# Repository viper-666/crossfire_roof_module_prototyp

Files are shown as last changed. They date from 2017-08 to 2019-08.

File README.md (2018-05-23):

# XF Roof Module

Deutsche Anleitung: [LIESMICH.md](https://github.com/viper-666/xf_roof_module/blob/master/LIESMICH.md)

This module allows you to open / close the Crossfire's soft top without having to press and hold the Open / Close button all the time.

Another feature is that you can set up the speed at which you can do this in the Arduino Sketch.
The default is 31 mph (50 kph) (variable "int GESCHWINDIGKEIT = 50" attention it is in kph not in mph) and should not be increased. If the speed at which you open the soft top is too high, this will damage your convertible top or the mechanics.

In addition, the windows are automatically raised after the convertible top is opened.
There is also an emergency stop function simply push the button, no matter which direction, again and the roof stops.

I have tested the module for several months without problems but it could damage your car. Therefore, a replica is done at your own risk!

## Handling

If you want to open or close the roof while the car stands simply press the switch short in the appropriate direction. It can take up to 2 seconds before the roof moves. If an error occurs it will piping.
During the journey, you can open or close the roof up to the set speed. 

Please note the following:

If you want to open the roof while driving, it is very important first to press the switch open and then to unlock the roof within 2 seconds.
If you unlock the roof first, the original CrossFire convertible module is interrupted and you have to close the roof again and wait a few seconds until you can open it.

When closing while driving up to the set speed, there is nothing else to do, just press the switch on close and after about 2 seconds the roof will close.
If you get over the set speed while opening or closing, the roof stops moving and you have to speed down under the set speed and the roof will complete the action.

## Lets start

First you have to build the hardware, so solder the board. Unfortunately, I do not have the knowledge to design a circuit board which you can etch.
But if you have created such a circuit board, please give me the file, I make the layout available so that everyone else can benefit from it.

Until then you have to build the circuit unfortunately as I on a perfboard.

## BOM Hardware

|Microcontroler:| |
|---|---|
|Value		|Quantily|
|Arduino Nano V3|1 |

|Resistors:| |
|---|---|
|Value|Quantily|
|1M |1 |
|2k2 |3 |
|5k |2 |
|22k |5 |
|100k |5 |
|560k |1 |
|200 |1 |

|Zener Diode:| |
|---|---|
|Value|Quantily|
|1N750 (4,7V)|1|

|Diode:| |
|---|---|
|Value|Quantily|
|1N4007|1|

|Voltage regulator:| |
|---|---|
|Value|Quantily|
|78L05Z (5V) TO92|1|

|Capacitors:| |
|---|---|
|Value|Quantily|
|100µF|2|
|100n|2|

|Transistors:| |
|---|---|
|Value|Quantily|
|BC547|5|

|Fuse:| |
|---|---|
|Value|Quantily|
|200mA|1|
|Fuse holder|1|

|Plug and socket:| |
|---|---|
|Value|Quantily|
|TE Connectivity AMP 1-1586041-4 VAL-U-LOK CONN HEADER 14POS R/A W/O PEGS|1 or 2|
|TE Connectivity AMP 1-1586019-4 VAL-U-LOK CONN RCPT HOUSING 14POS 4.2MM|1 or 2|
|TE Connectivity AMP 1586315-1 CONN TERM SOCKET 18-22AWG TIN|14 or 28|

But you can take any other socket and plug as long as they have at least 8 contacts.

## Building the hardware

A perfboard measuring 77mm x 80mm is required for assembly.

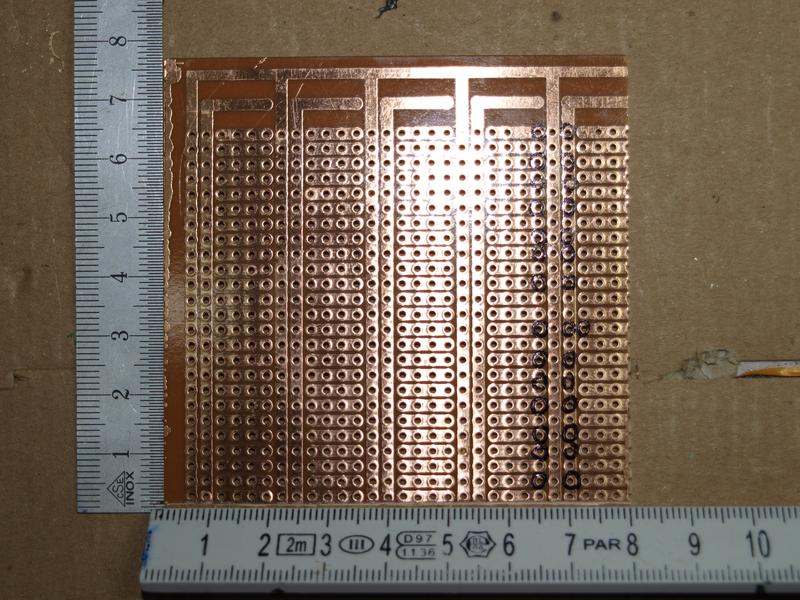
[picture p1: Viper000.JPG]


First I soldered the two sockets. For the roof module only the lower one is required, the upper one guides the other inputs and outputs of the Arduino Nano to the outside. This I have made for future extensions of the functions.
In order for the socket to fit, the holes of the circuit board must be inflated.

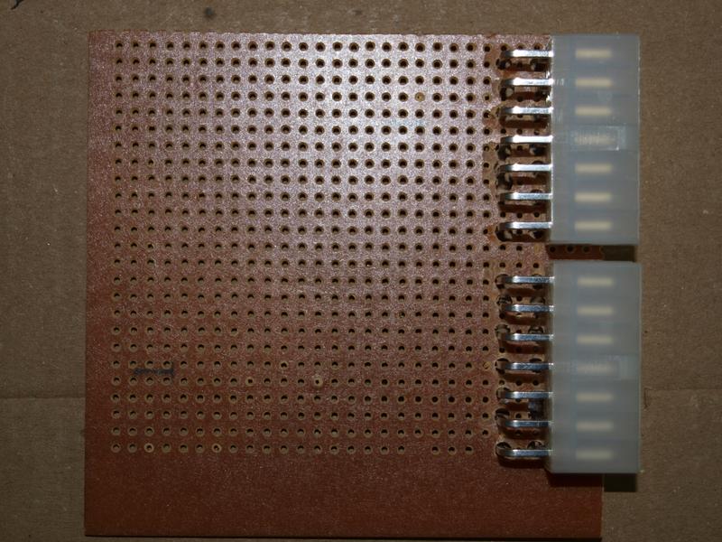
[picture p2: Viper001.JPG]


Subsequently, I have constructed the board according to the [schematic](https://github.com/viper-666/xf_roof_module/blob/master/Dachmodul.pdf):

At the bottom of the Arduino Nano, on the right the 12-18V to 5V voltage conversion and next to the fuse holder.
Above the Arduinno Nano the 5 transistors with the associated components.
Then make the missing connections with cables. And do not let the cable chaos deter you. 

You can omit the green socket and the cabling if you want to do without the extensibility to additional other functions.

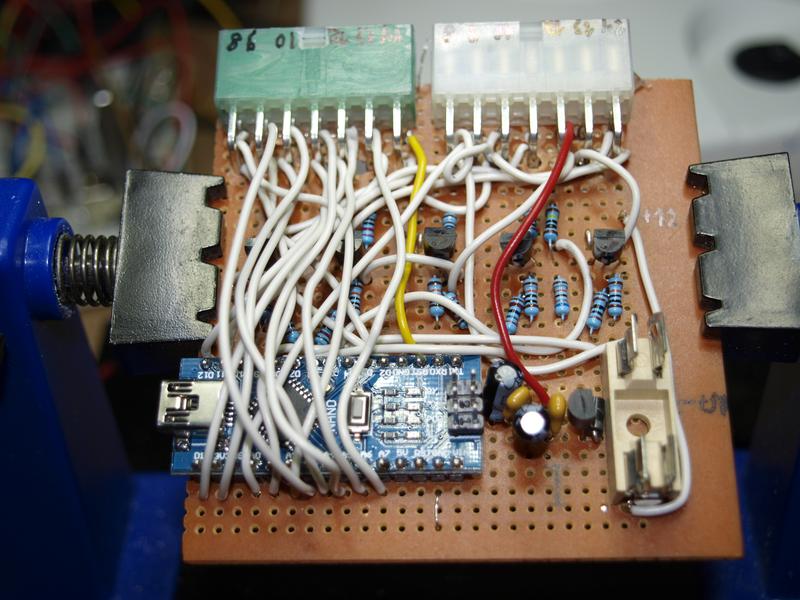
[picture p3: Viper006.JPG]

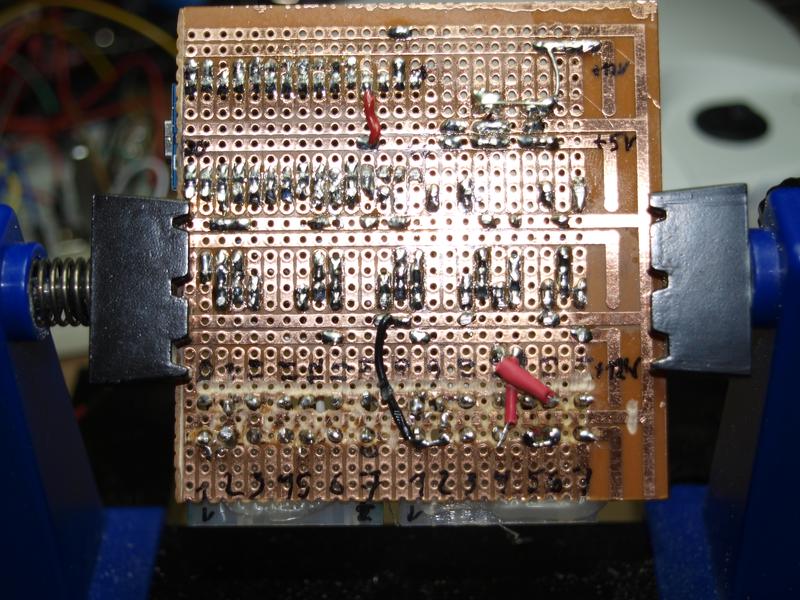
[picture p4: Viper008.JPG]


The plug with the cables is created according to the following [schema](https://github.com/viper-666/xf_roof_module/blob/master/Wiring.pdf) and integrated into the Crossfire cable harness.
The PINs marked in blue belong to the corresponding PINs of the connector.
The pins for the plug should be crimped onto the stripped cable ends with a crimping tool. If you do not have a crimping pliers, it is cheap, you can get it for 10-20 $ or you can solder the cable ends with the pins.

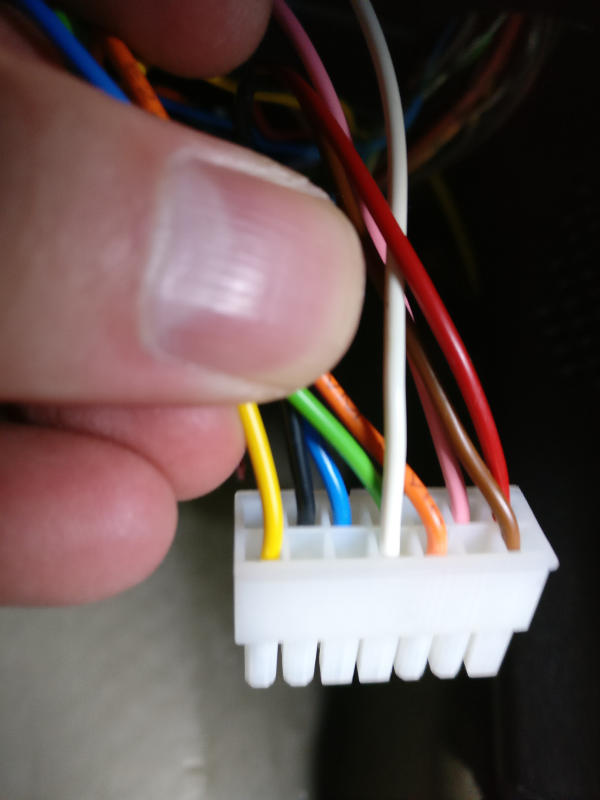
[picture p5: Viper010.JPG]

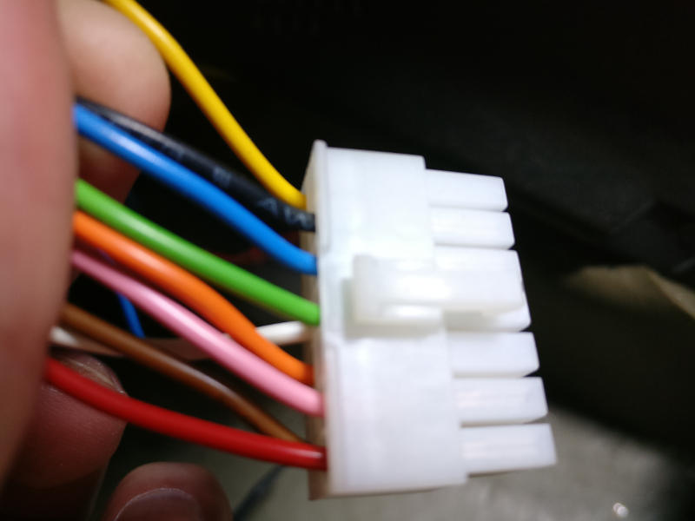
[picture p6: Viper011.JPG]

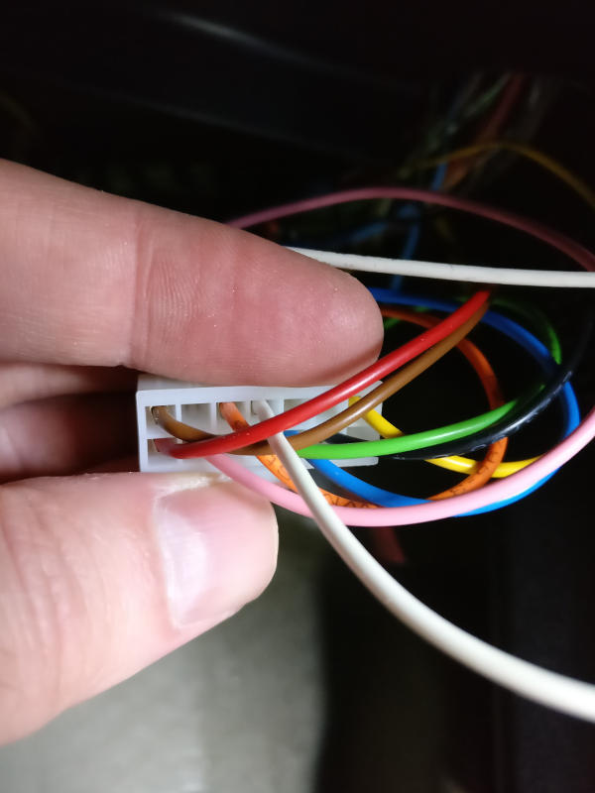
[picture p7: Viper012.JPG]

Build of the prototyp-PCB

This is how the finished module with the printed housing looks like:

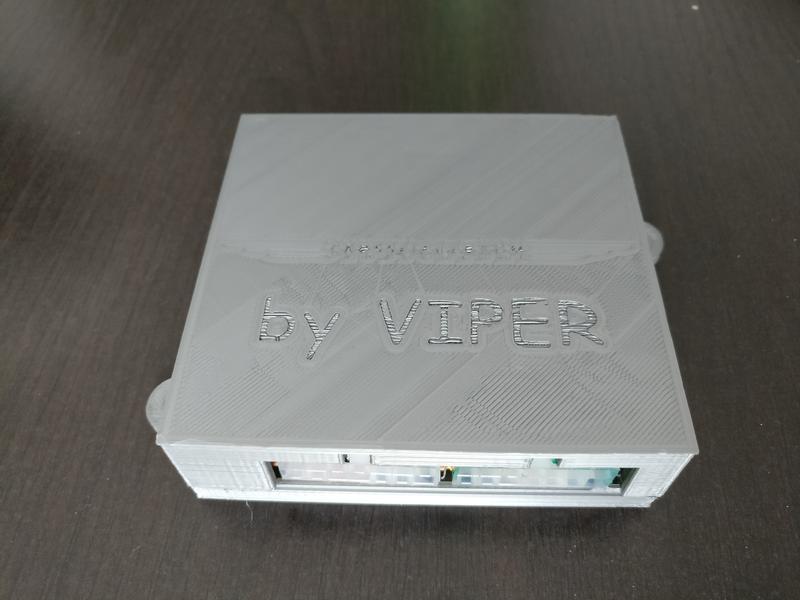
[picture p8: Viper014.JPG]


I recommend the construction of a deactivation plug, which is inserted in case of problems or sale of the car instead of the roof module. Thus, the severed lines are reconnected and the "original state" is restored.
Simply connect the following pins for a socket:

|A|B|
|---|---|
|PIN 3|PIN 11|
|PIN 7|PIN 12|
|PIN 9|PIN 13|

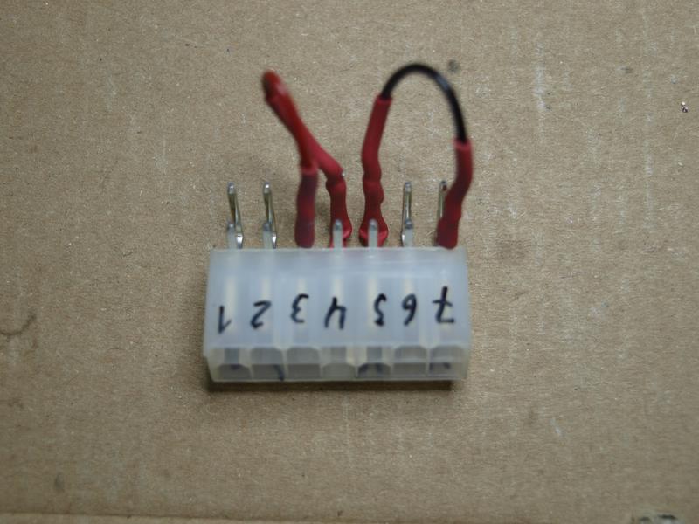
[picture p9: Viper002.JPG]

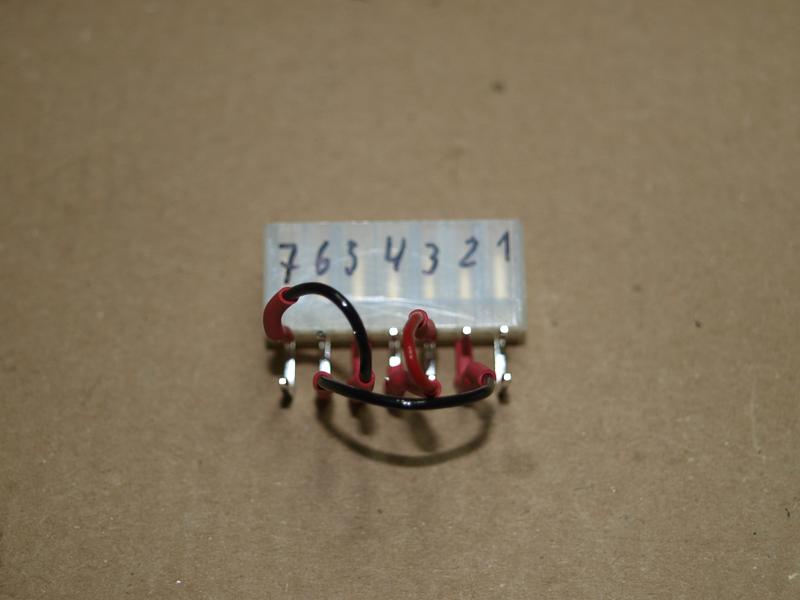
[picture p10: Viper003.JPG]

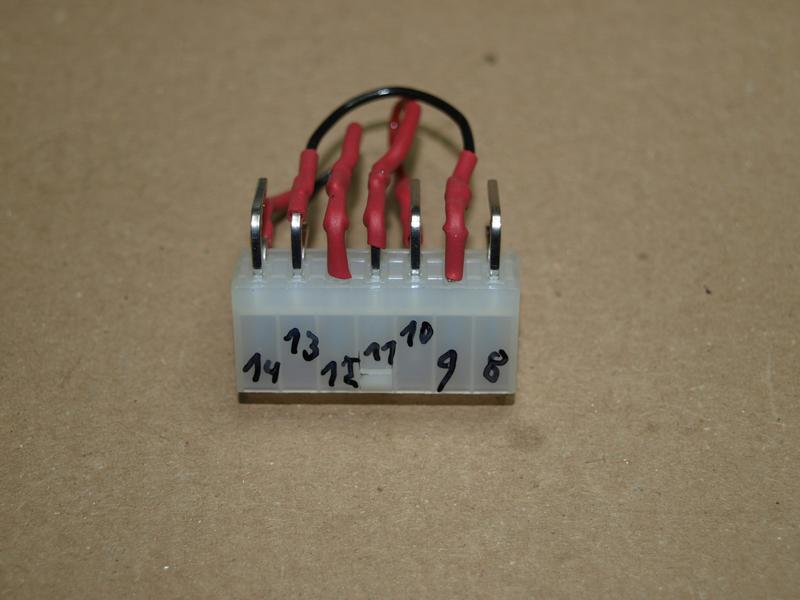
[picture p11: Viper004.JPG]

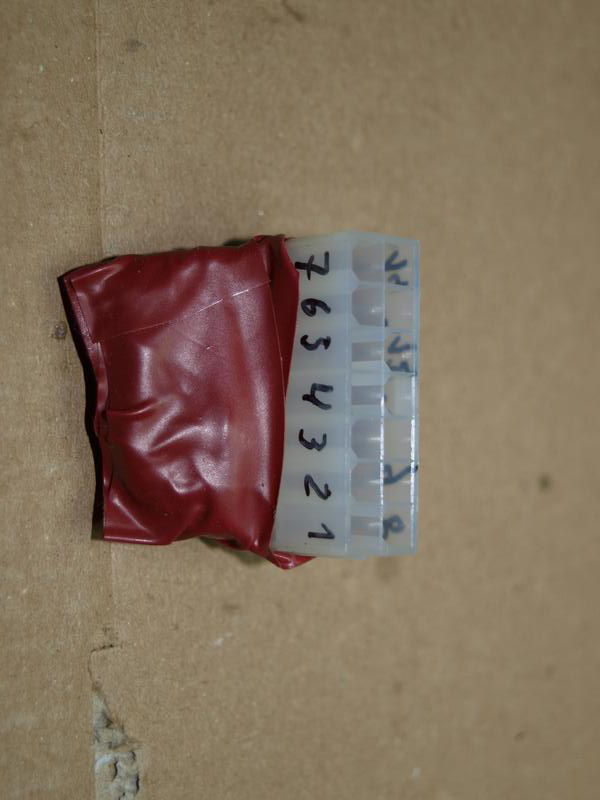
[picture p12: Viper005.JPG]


## Installing of the firmware

Simply use the [Sketch](https://github.com/viper-666/xf_roof_module/blob/master/Crossfire_Dachmodul-4.ino) with the [ARDUINO IDE](https://www.arduino.cc/en/Main/Software) to the Arduino.

## Installation in the Crossfire

The plug created in the previous section with the cables is now wired according to the following [schema](https://github.com/viper-666/xf_roof_module/blob/master/Wiring.pdf) in the Crossfire.

I recommend soldering the cables and isolating them with a shrink tube.

We start at the roof switch. To get to the roof switch, open the cup holder, grasp the opening with the fingers and lift the silver bezel at the front of the circuit until it is released from the grid.

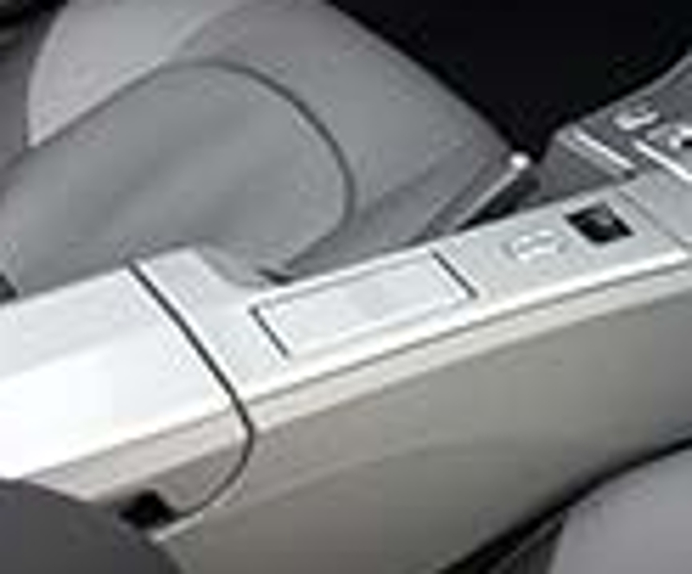
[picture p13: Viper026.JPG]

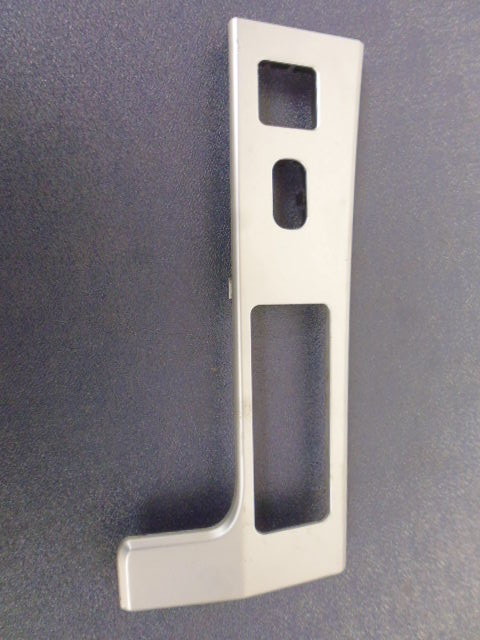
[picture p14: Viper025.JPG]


The white / purple cable must then be cut and the pink cable of our plug must be connected with the part of the white / purple cable which is still hanging on the plug. The black cable of the plug comes to the now still open end of the white / purple cable.
The white cable of our plug comes to the brown / yellow cable.

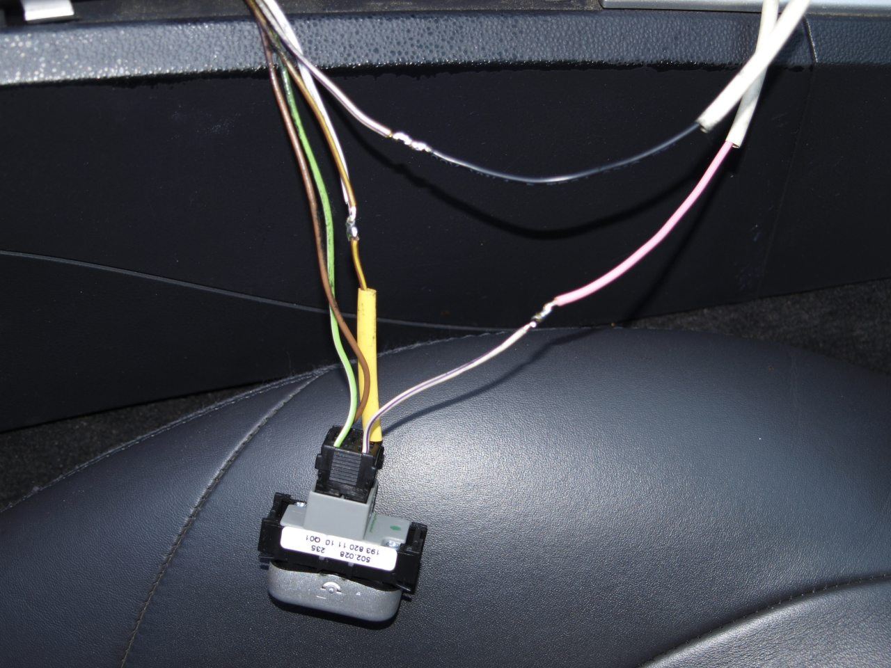
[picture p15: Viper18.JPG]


Now we have to lift the carpet in the passenger footwell and fold in the direction of the seat and remove the white styrophoric plate.

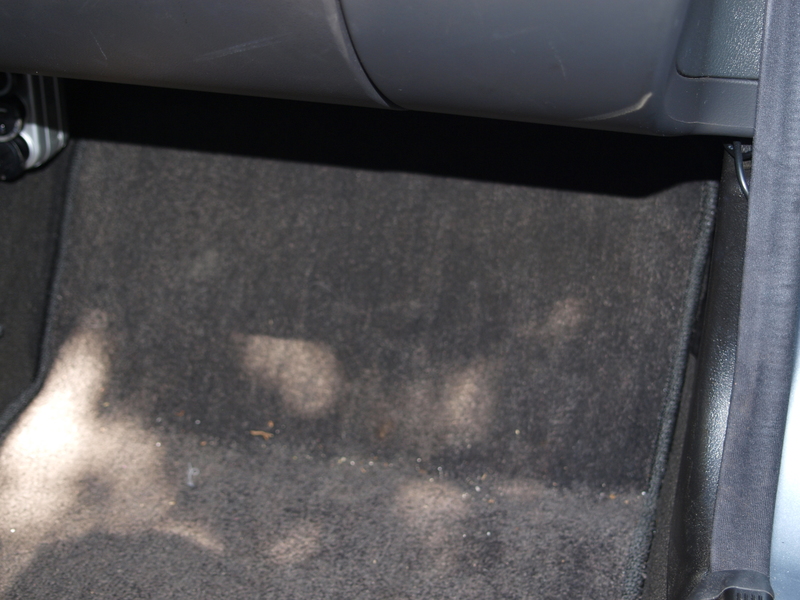
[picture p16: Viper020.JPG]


The silver plate is secured with 3 black plastic nuts, which must be removed.

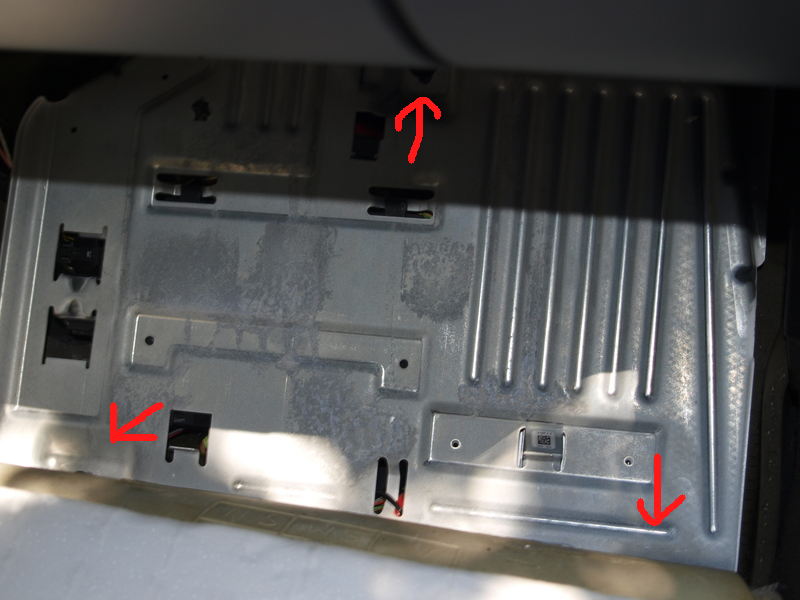
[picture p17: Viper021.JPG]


Now we can fold this towards the seat. The wiring harness with the required cables is on the upper right.

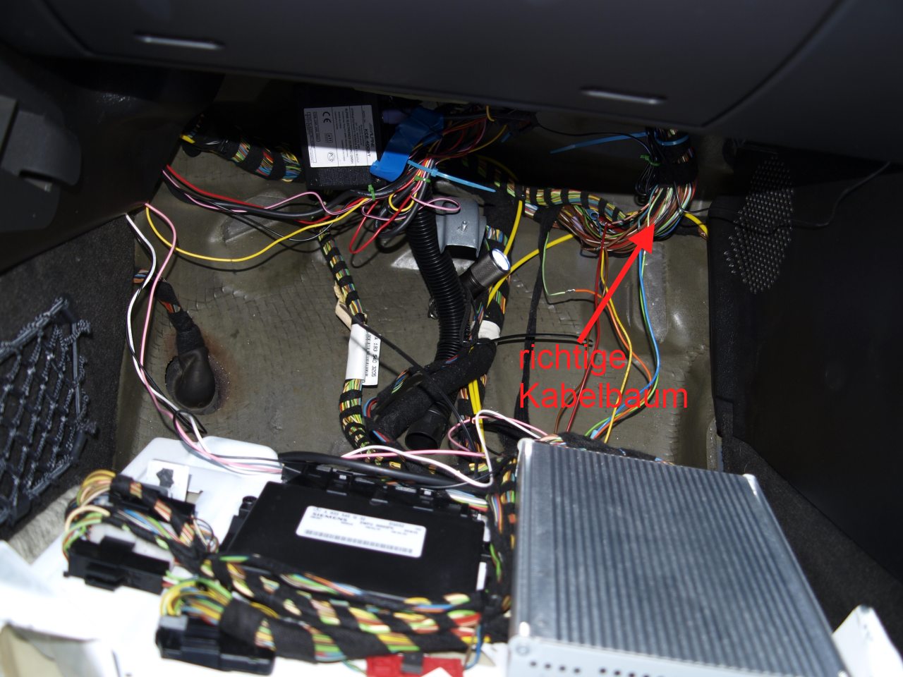
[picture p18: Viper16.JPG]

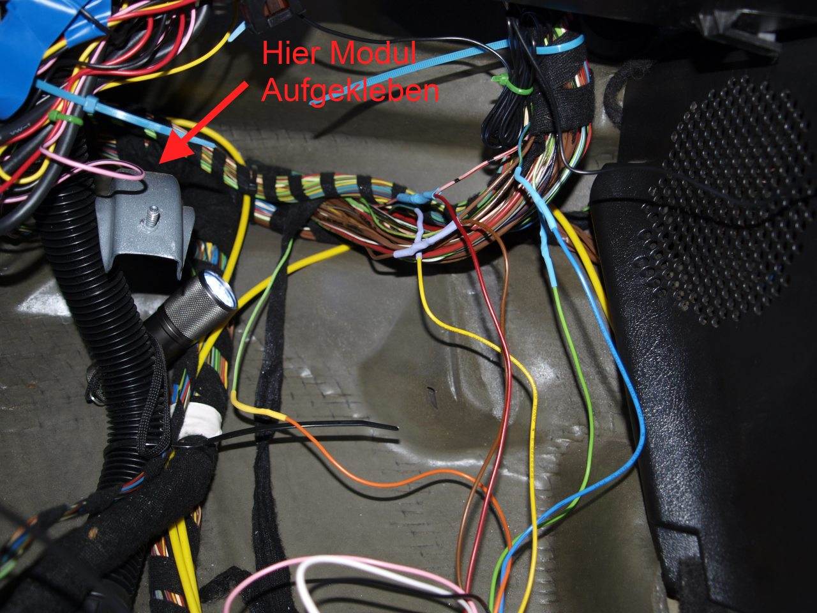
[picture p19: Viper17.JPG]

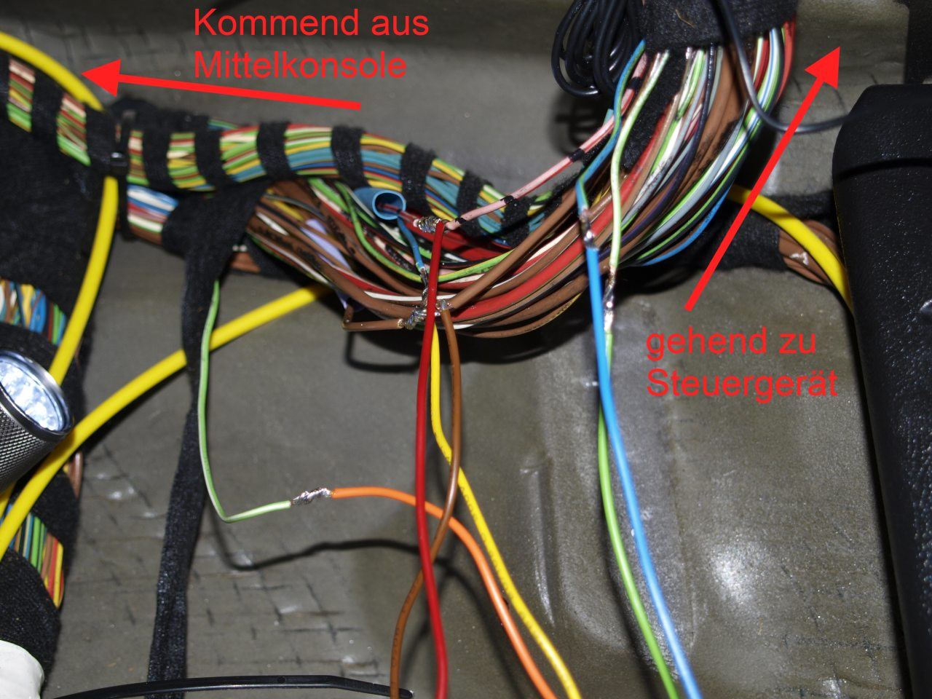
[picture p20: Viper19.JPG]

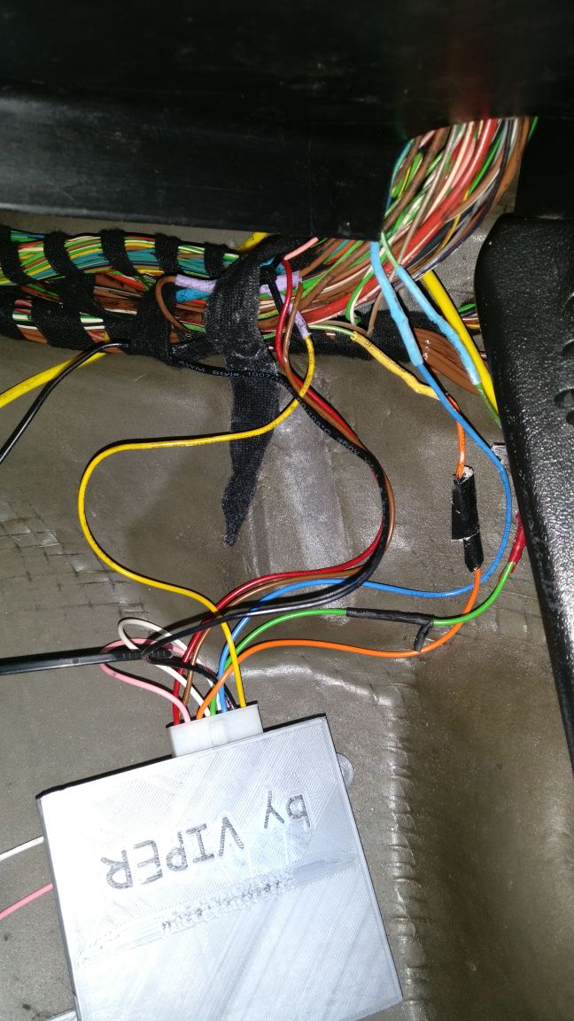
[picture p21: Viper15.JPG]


In this harness we have to look for the following cables:
- Pink / Red / Black (+ 12V) which we connect with the red cable of the plug
- Brown (ground) this we will connect with the brown cables of the plug
- Blue / Green (BCM PIN 56) this must be cut through and the cable end which goes to the left to the center console comes the yellow and to the other end the blue cable of the plug
- Green / White (BCM PIN 74) you have to be careful, the cable is available several times. It is best to test with a multimeter in the continuity test whether the correct cable from the control unit PIN 74 has caught. Then this must cut through and to the cable end which goes to the left to the center console comes the orange and to the other end the green cable of the plug

If there is still enough space in the box for the RCM module and the control unit, the cables can also be tapped directly at the connector of the control unit and you only have to pass the three cables for the roof switch through the cable harness.
Advantage is, the better accessibility and one the cables unambiguously at the connector finds, since there the PIN numbers are readable.

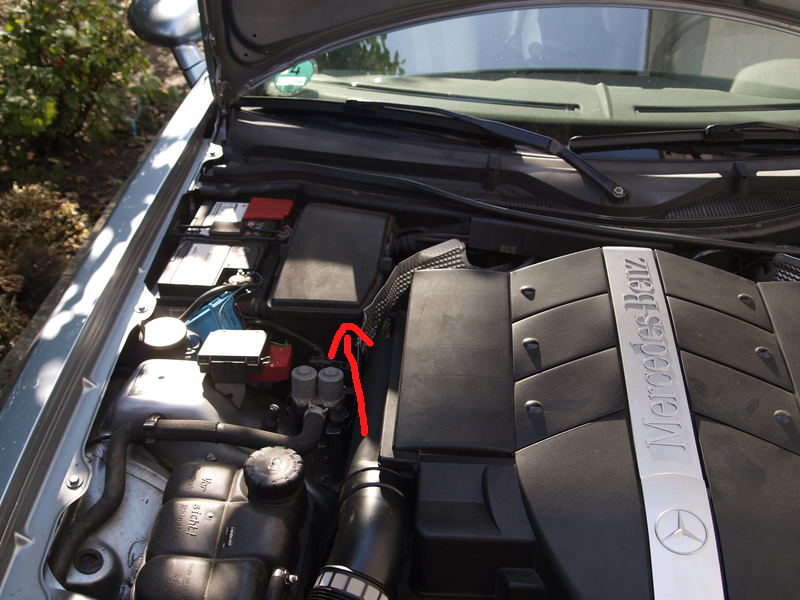
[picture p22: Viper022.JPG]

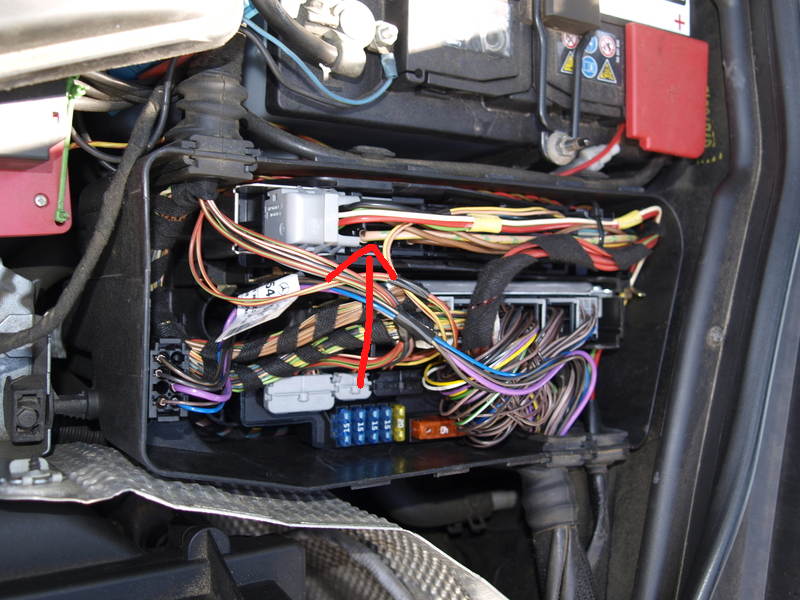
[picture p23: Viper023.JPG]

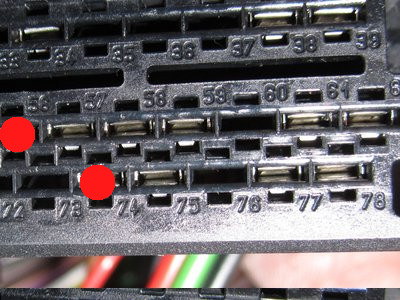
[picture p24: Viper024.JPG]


## Built With

* [ARDUINO](https://www.arduino.cc/en/Main/Software) - I used the Version 1.6.8
* [EAGLE](https://www.autodesk.com/products/eagle/free-download) - The Software is free for peronal use but you have to make an Autodesk Account.

## Author

* **Andre Holtkamp** - [viper-666](https://github.com/viper-666)

## License

This project is licensed under the GNU General Public License v3.0 License - see the [LICENSE](https://github.com/viper-666/xf_roof_module/blob/master/LICENSE) file for details.

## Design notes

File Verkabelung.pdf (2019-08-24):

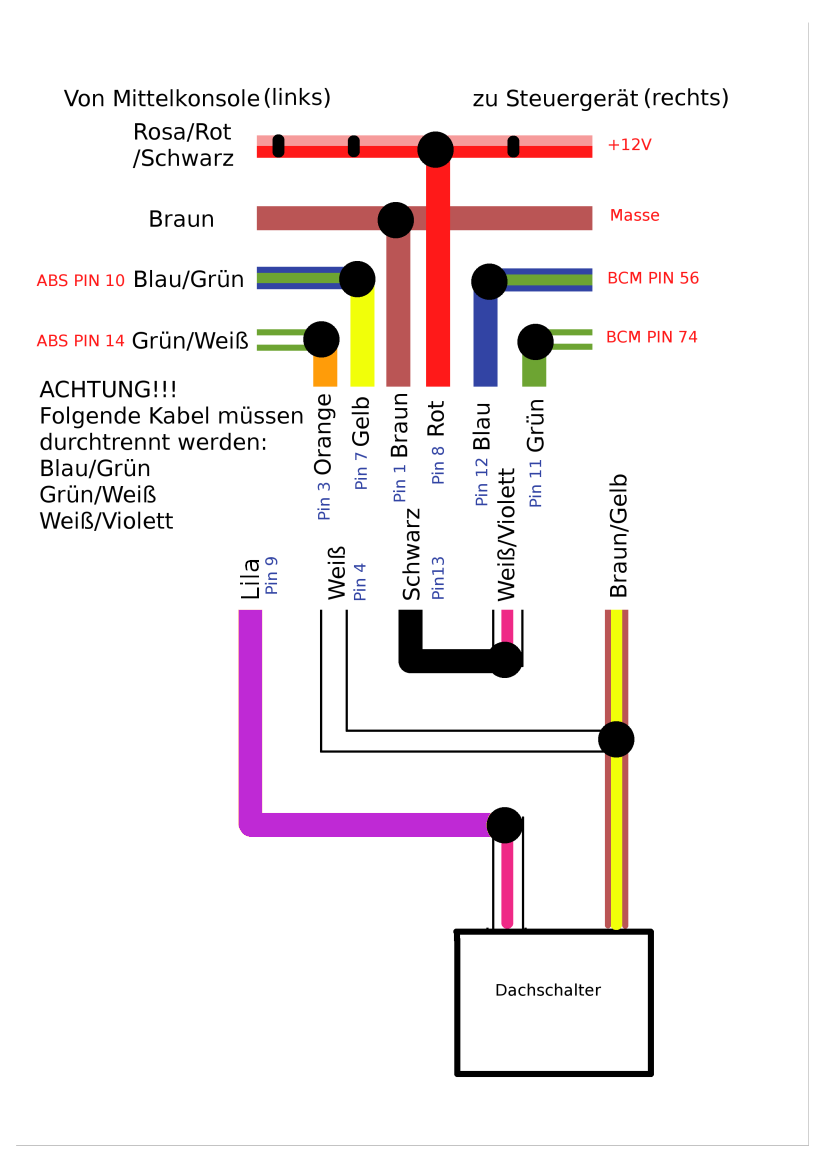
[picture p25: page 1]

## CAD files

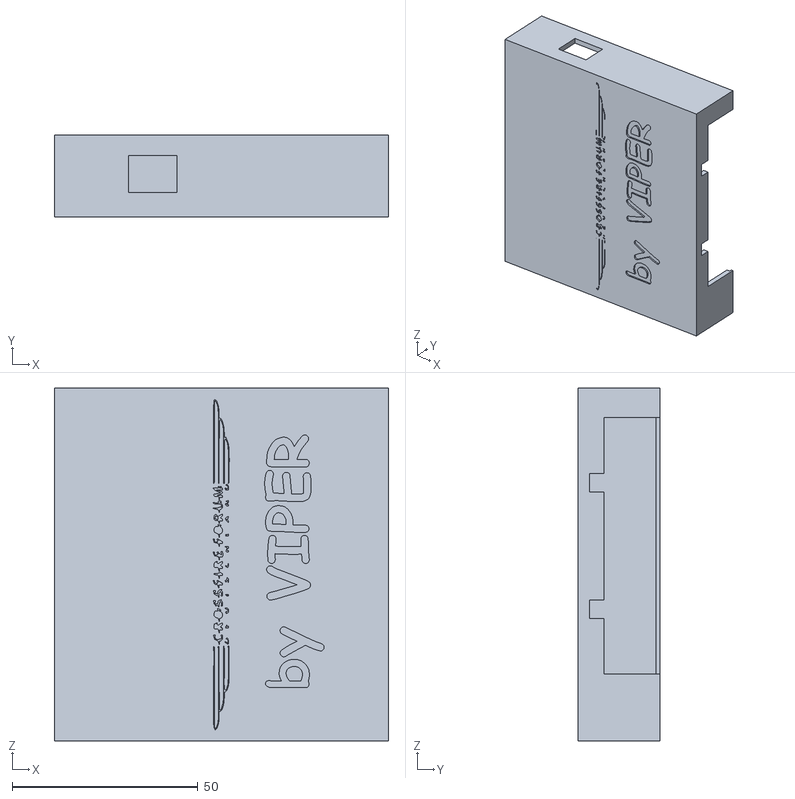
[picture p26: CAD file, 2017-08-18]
Gehause_oben_Dachmodul.stl
90.0 x 22.0 x 95.0

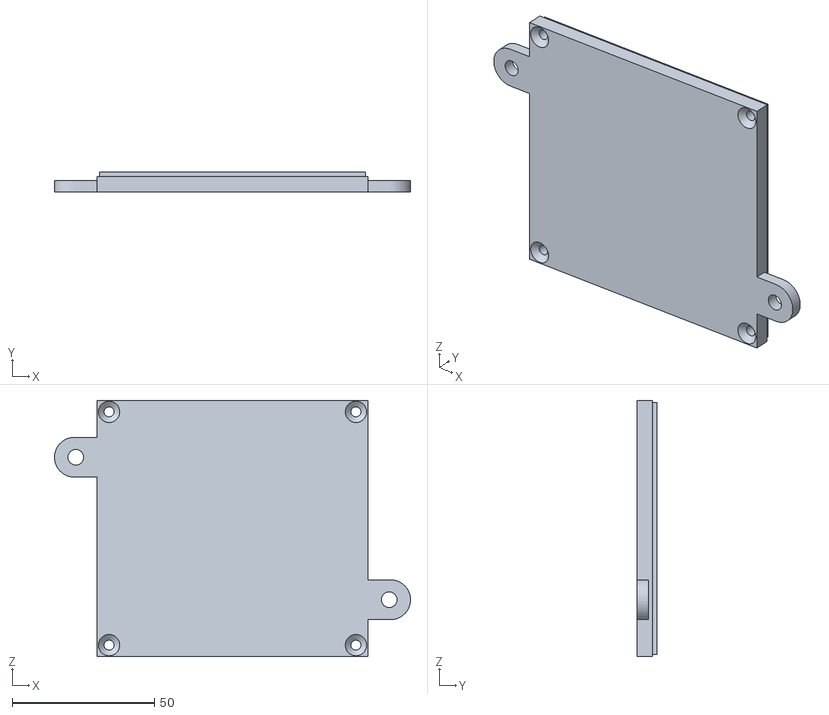
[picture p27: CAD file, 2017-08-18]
Gehaeuse_unten_Dachmodul.stl
125.0 x 7.00 x 90.0

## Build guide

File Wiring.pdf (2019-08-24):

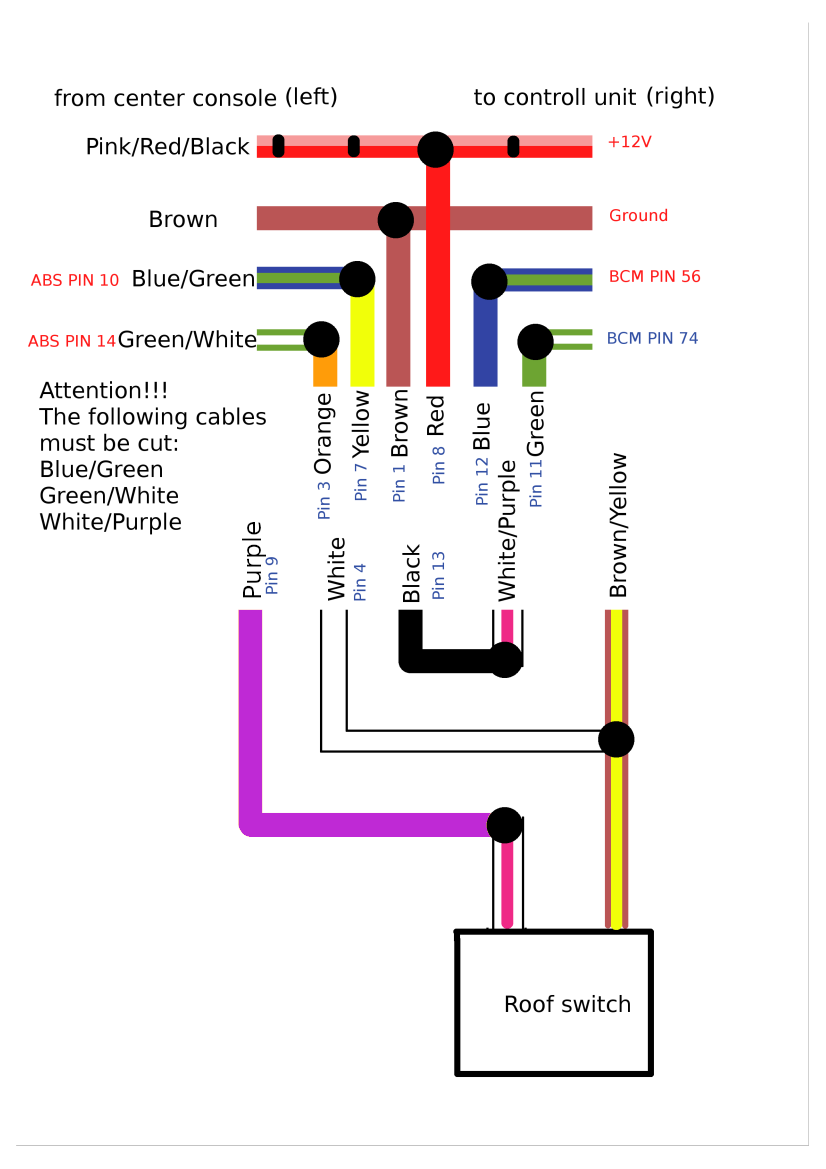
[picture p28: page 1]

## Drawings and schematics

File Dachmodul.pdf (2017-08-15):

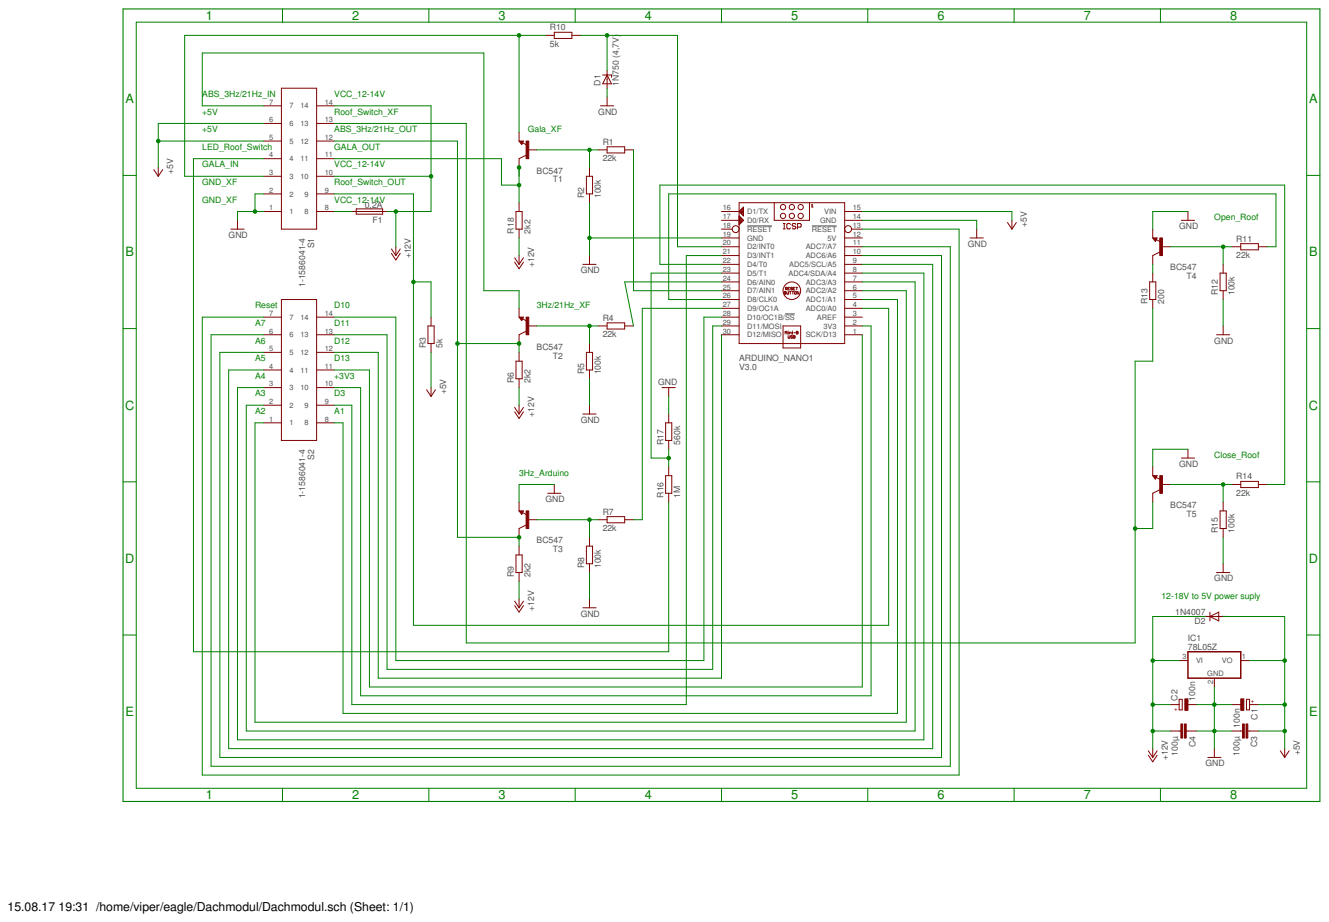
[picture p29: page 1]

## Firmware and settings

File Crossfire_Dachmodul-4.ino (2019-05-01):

/**
 * Chrysler Crossfire Roadster Dachmodul
 * Funktionen:
 * -Halten des Tasters für Dach-Auf und Dach-Zu entfällt, einfach Taster 1x kurz drücken.
 * -Öffnen und Schließen des Daches bis zu x km/h
 * Skript von Andre Holtkamp AKA Viper 
 * V1.1 vom 05/2018 
 * https://crossfire-forum-deutschland.de/viewtopic.php?f=8&t=694#p5604
 * 
 * Anschluss Dachsteuerung PINS Arduino
 * PIN2 = Frequenz Eingang (Radfrequenz 6Hz pro km/h Grün/Weiß vom Steuergerät PIN 74 kommend)
 * PIN8 = Dach auf zum Transistor
 * PIN4 = Dach zu zum Transistor
 * PIN5 = LED-Dachschalter
 * PIN9 = erzeugte 3Hz
 */
 
 #define OUT_PIN_AUF 8  // Arduino Digital I/O pin für Ausgang Dach Auf zum Transistor
 #define OUT_PIN_ZU 4  // Arduino Digital I/O pin für Ausgang Dach Zu zum Transistor
 #define LED_SCHALTER 5  // Arduino Digital I/O pin für Eingang Schalter LED im Dachschalter AN/AUS
 #define FREQ_3HZ 9      // Arduino Digital I/O pin für Ausgang 3Hz Erzeugung
 #define OUT_PIN_F 6  // Arduino Digital I/O pin für Ausgang schaltet Transistor für ABS-Steuersignal 3Hz/21Hz (HIGH=PIN 56 Steuergerät durchgeschaltet)
 #define OUT_PIN_F1 7  // Arduino Digital I/O pin für Ausgang  schaltet Transistor für Radfrequenz Geschwindigkeitssignal (HIGH=PIN 74 Steuergerät durchgeschaltet)
 #define BUZZER 10  // Arduino Digital I/O pin für BUZZER

 long f = 0;
 int FENSTERZU = 0;  // Variable Fenster ZU/AUF
 int FENSTERZUA = 0;  // Variable Fenster ZU/AUF automatische schließen Fenster
 int LED = 0;  // Variable LED AN/AUS
 int IN_PIN_AUF_ZU = 0;  // Arduino Analog I/O pin für Ausgang Dach Auf
 int AKTIVIERT = 0;   // Speichert ob das Dach gerade göffnet/geschlossen wird
 int SPEED = 0;   // Speichert ob das Dach gerade göffnet/geschlossen wird und die Geschwindigkeit überschritten wurde
 int  HOLD1 = 0;   // Variable um das Dach bei Geschwindigkeiten zwischen 7km/h bis GESCHWINDIGKEIT zu freizuschalten
 int  HOLD_AN_AUS = 0;   // Variable um das Dach bei Geschwindigkeiten zwischen 7km/h bis GESCHWINDIGKEIT zu freizuschalten
 String MELDUNG = "";   // Debugvariable
 int ZFZU = 0;   //Zählvariable
 int ANALOG_EINGANG0 = 0;   //Zählvariable unsigned long currentTime; // Zeitvariable aktuell
unsigned long loopTime = 0; // Zeitvariable gespeichert
unsigned long loopTimeMAX = 0; // Zeitvariable Max Öffnen7Schließen gespeichert
unsigned long loopTimeFZU = 0; // Zeitvariable gespeichert
unsigned long loopTimeHOLD = 0; //Zeitvariable um zwischen 7km/h bis GESCHWINDIGKEIT freizuschalten

// Frequenz messen
unsigned long Timestamp;
volatile unsigned long count;

// Diese Variablen können angepasst werden
 int KARENZZEIT = 1000; // Karenzzeit zwischen zwei Tastendrücken in ms
 int DOPPELKLICKZEIT = 300; // Zeit in zwischen Doppelklick zum Fensterschließen ms
 long MAXLAUFZEIT = 30000; // Zeit welche das Dachöffnen/schließen Signal max. geschaltet wird in ms
 const unsigned long Tmess = 200; // Messfrequenz Frequenzmessung in ms
 int TimeHOLD = 10000; // Zeitvariable wie lange zwischen 7km/h bis GESCHWINDIGKEIT freigeschaltet wird in ms
 int TimeHOLD_AN = 2000; // Zeitvariable wann Ausgang Dach AUF/ZU geschaltet wird in ms
 int GESCHWINDIGKEIT = 55; //Geschwindigkeit bis zu der das Dach geöffnet werden kann

void setup() {

  // Serielle Schnittstelle starten
    Serial.begin(115000);
 
  // Setup TASTER
  pinMode(LED_SCHALTER,INPUT);

  // Setup Ausgänge
  pinMode(OUT_PIN_AUF,OUTPUT);
  pinMode(OUT_PIN_ZU,OUTPUT);
  pinMode(OUT_PIN_F,OUTPUT);  
  pinMode(OUT_PIN_F1,OUTPUT);
  pinMode(FREQ_3HZ, OUTPUT);
  
    // Activiere internen pull-up
  digitalWrite(LED_SCHALTER,LOW);
 
  //Schalte Frequenz vom Radsensor durch
    digitalWrite(OUT_PIN_F, HIGH); //ABS-Steuersignal durchschalten 3Hz
    digitalWrite(OUT_PIN_F1, HIGH); //Radfrequenz durchschalten Geschwindigkeitssignal

  // Frequenz
    attachInterrupt(0, ISR_f, RISING); // Interrupt an Pin2

 // Erste Zeile für Frequenzmessung auf Serieller Schnittstelle ausgeben   
     Serial.print("Frequenz");Serial.print("\t");
     Serial.print("Debugmeldung"); Serial.print("\t");
     Serial.print("Analogeingang");Serial.println("\t");
     Serial.print("Aktiviert");Serial.print("\t\t");
     Serial.print("Hold");Serial.print("\t\t"); 
     Serial.print("HOLD_AN_AUS");Serial.print("\t\t");
     Serial.print("LED");Serial.print("\t\t");
     Serial.print("LED-Schalter");Serial.print("\t\t");
     Serial.print("ZFZU");Serial.print("\t\t");
     Serial.println();

  // Timer 1 erzeugen
  noInterrupts();           // Alle Interrupts temporär abschalten
  TCCR1A = 0;
  TCCR1B = 0;
  TCNT1 = 56066;            // Timer auf 3Hz stellen
  TCCR1B |= (1 << CS12);    // 256 als Prescale-Wert spezifizieren
  interrupts();             // alle Interrupts scharf schalten
}

// 3Hz Frequenz erzeugen
ISR(TIMER1_OVF_vect)        
{
  TCNT1 = 56066;             // Timer auf 3Hz stellen
  digitalWrite(FREQ_3HZ, digitalRead(FREQ_3HZ) ^ 1); // Port HIGH/LOW
}

void loop() {


// Analogwert vom Dacheingangsschalter lesen und auf Serieller Schnittstelle ausgeben
  ANALOG_EINGANG0 = analogRead(IN_PIN_AUF_ZU);    // Schalter Analog einlesen


// Frequenz
   if ( millis()-Timestamp > Tmess){
    f = (count * long(1000))/ Tmess;
  
// Debug auf Serieller Schnittstelle ausgeben
     Serial.print(f);Serial.print("\t\t");
     Serial.print(MELDUNG); Serial.print("\t\t");
     Serial.print(ANALOG_EINGANG0);Serial.print("\t"); 
     Serial.print(AKTIVIERT);Serial.print("\t");
     Serial.print(HOLD1);Serial.print("\t");  
     Serial.print(HOLD_AN_AUS);Serial.print("\t");
     Serial.print(LED);Serial.print("\t");
     Serial.print(digitalRead(LED_SCHALTER));Serial.print("\t");
     Serial.print(ZFZU);Serial.print("\t");
     Serial.println("\t");

// Auswertung Taster**************************************************************************************************************************
   
// Überprüfe ob Taster Dach-AUF gedrückt wird
if ((millis() >= (loopTime + KARENZZEIT)) && (HOLD_AN_AUS == 0) && (f < (GESCHWINDIGKEIT*6)) && (digitalRead(LED_SCHALTER) == HIGH) && ((ANALOG_EINGANG0 > 10) && (ANALOG_EINGANG0 < 300)) && (AKTIVIERT == 0)) {
    //Schalte Frequenz an:
    F3HZ_AN();   
    // schalte Ausgang an:
    digitalWrite(OUT_PIN_AUF, HIGH);
    AKTIVIERT = 1; // Dach auf/zu aktiviert
    FENSTERZU = 1;
    FENSTERZUA = 1;
    HOLD_AN_AUS = 1;
    loopTime = millis(); // Laufzeit setzen
    loopTimeMAX = millis(); // Laufzeit setzen
    HOLD1 = 0;
    MELDUNG = "Taster AUF";
  } 

 // Überprüfe ob Taster Dach-ZU gedrückt wird
if ((millis() >= (loopTime + KARENZZEIT)) && (HOLD_AN_AUS == 0) && (f < (GESCHWINDIGKEIT*6)) && (digitalRead(LED_SCHALTER) == HIGH) && (ANALOG_EINGANG0 < 10)) {
    //Schalte Frequenz an:
    F3HZ_AN();  
   // schalte Ausgang an
    digitalWrite(OUT_PIN_ZU, HIGH);
    HOLD_AN_AUS = 2;
    AKTIVIERT = 1;// Dach auf/zu aktiviert
    FENSTERZU = 1;
    FENSTERZUA = 2;
    loopTime = millis(); // Laufzeit setzen
    loopTimeMAX = millis(); // Laufzeit setzen
    HOLD1 = 0;
    MELDUNG = "Taster Zu";
  } 

// Überprüfe ob Taster Dach-AUF gedrückt wird und LED im Taster nicht an ist
if ((digitalRead(LED_SCHALTER) == LOW) && (f < (GESCHWINDIGKEIT*6)) && ((ANALOG_EINGANG0 > 10) && (ANALOG_EINGANG0 < 300)) && (AKTIVIERT == 0)) {
    F3HZ_AN();
    // schalte Ausgang an
    //digitalWrite(OUT_PIN_AUF, HIGH);
    HOLD1 = 1;
    HOLD_AN_AUS = 1;
    loopTimeHOLD = millis();
    AKTIVIERT = 1;// Dach auf/zu aktiviert
    FENSTERZU = 1;
    FENSTERZUA = 1;
    loopTime = millis(); // Laufzeit setzen
    loopTimeMAX = millis(); // Laufzeit setzen
    MELDUNG = "Taster AUF ohne LED*";
      } 

      
 // Überprüfe ob Taster Dach-ZU gedrückt wird wird und LED im Taster nicht an ist
if ((digitalRead(LED_SCHALTER) == LOW) && (f < (GESCHWINDIGKEIT*6)) && (ANALOG_EINGANG0 < 10) && (AKTIVIERT == 0)) {
    // schalte Frequenz
    F3HZ_AN();
    //digitalWrite(OUT_PIN_ZU, HIGH);
    HOLD1 = 1;
    HOLD_AN_AUS = 2;
    loopTimeHOLD = millis();
     AKTIVIERT = 1;// Dach auf/zu aktiviert
     FENSTERZU = 1;
     FENSTERZUA = 2;
    loopTime = millis(); // Laufzeit setzen
    loopTimeMAX = millis(); // Laufzeit setzen
    MELDUNG = "Taster ZU ohne LED*";
      } 

// Überprüfe ob Taster Dach-AUF gedrückt, Dach schon geöffnet oder geschlossen wird und KARENZZEIT vergangen ist (STOP)
if ((millis() >= (loopTime + KARENZZEIT)) && (AKTIVIERT == 1) && ((ANALOG_EINGANG0 > 10) && (ANALOG_EINGANG0 < 300))) {
    loopTime = millis(); // Laufzeit setzen
    MELDUNG = "STOP AUF";
    STOP (0);
      } 

 // Überprüfe ob Taster Dach-ZU gedrückt, Dach schon geöffnet oder geschlossen wird und KARENZZEIT vergangen ist (STOP)
if ((millis() >= (loopTime + KARENZZEIT)) && (AKTIVIERT == 1) && (ANALOG_EINGANG0 < 10)) {
    loopTime = millis(); // Laufzeit setzen
    MELDUNG = "STOP ZU";
    STOP (0);
      } 


// Fenstersteuerung ***************************************************************************************************************************
// Fenster automatisch schließen nach Dach öffnen
    if ((millis() >= (loopTimeFZU + 4 * DOPPELKLICKZEIT)) && (ZFZU==1) && (FENSTERZUA == 1)) {
    digitalWrite(OUT_PIN_AUF, HIGH);
    ZFZU++;
    MELDUNG = "Fenster schließen";
    }
  
    if (millis() >= (loopTimeFZU + (5 * DOPPELKLICKZEIT)) && (ZFZU==2) && (FENSTERZUA == 1)) {
    digitalWrite(OUT_PIN_AUF, LOW);
    ZFZU++;
    }
    
    if (millis() >= (loopTimeFZU + (6 * DOPPELKLICKZEIT)) && (ZFZU==3) && (FENSTERZUA == 1)) {
    digitalWrite(OUT_PIN_AUF, HIGH);
    ZFZU++;
    }
    
    if (millis() >= (loopTimeFZU + (22 * DOPPELKLICKZEIT)) && (ZFZU==4) && (FENSTERZUA == 1)) {
    digitalWrite(OUT_PIN_AUF, LOW);
    ZFZU = 0;
    FENSTERZUA = 0;
    }


// Fenster automatisch schließen nach Dach schließen
    if ((millis() >= (loopTimeFZU + 4 * DOPPELKLICKZEIT)) && (ZFZU==1) && (FENSTERZUA == 2)) {
    digitalWrite(OUT_PIN_ZU, HIGH);
    ZFZU++;
    MELDUNG = "Fenster schließen";
    }
  
    if (millis() >= (loopTimeFZU + (5 * DOPPELKLICKZEIT)) && (ZFZU==2) && (FENSTERZUA == 2)) {
    digitalWrite(OUT_PIN_ZU, LOW);
    ZFZU++;
    }
    
    if (millis() >= (loopTimeFZU + (6 * DOPPELKLICKZEIT)) && (ZFZU==3) && (FENSTERZUA == 2)) {
    digitalWrite(OUT_PIN_ZU, HIGH);
    ZFZU++;
    }
    
    if (millis() >= (loopTimeFZU + (22 * DOPPELKLICKZEIT)) && (ZFZU==4) && (FENSTERZUA == 2)) {
    digitalWrite(OUT_PIN_ZU, LOW);
    ZFZU = 0;
    FENSTERZUA = 0;
    }



//**************************************************************************************************************************

 // LED im Taster

if ((digitalRead(LED_SCHALTER) == HIGH) && (AKTIVIERT == 1)) {
 LED = 1;
 MELDUNG = "LED=1";
}

if ((digitalRead(LED_SCHALTER) == LOW) && (AKTIVIERT == 1) && (LED == 1)) {
 STOP (1);
 LED = 0;
 MELDUNG = "Stop LED";
}

// Max. Laufzeit wo der Tastendruck Dach AUF/ZU simuliert wird ist abgelaufen (STOP)
if ((millis() >= (loopTimeMAX + MAXLAUFZEIT)) && (AKTIVIERT == 1) && (ANALOG_EINGANG0 > 300)) {
    loopTime = millis(); // Laufzeit setzen
    loopTimeMAX = millis(); // Laufzeit setzen
    MELDUNG = "Laufzeit abgelaufen";
    STOP (0);
  } 

// Dach_AUF ist gedrückt ohne LED und Wartezeit abgelaufen
if ((millis() >= (loopTimeHOLD + TimeHOLD_AN)) && (HOLD1 == 1) && (HOLD_AN_AUS == 1) && (ANALOG_EINGANG0 > 300)) {
    MELDUNG = "Schalte_Auf";
    digitalWrite(OUT_PIN_AUF, HIGH);
  } 

// Dach_ZU ist gedrückt ohne LED und Wartezeit abgelaufen
if ((millis() >= (loopTimeHOLD + TimeHOLD_AN)) && (HOLD1 == 1) && (HOLD_AN_AUS == 2) && (ANALOG_EINGANG0 > 300)) {
    MELDUNG = "Schalte_Zu";
    digitalWrite(OUT_PIN_ZU, HIGH);
  } 

// Max. Laufzeit Freischaltung ist abgelaufen
if ((millis() >= (loopTimeHOLD + TimeHOLD)) && (HOLD1 == 1) && (AKTIVIERT == 0) && (ANALOG_EINGANG0 > 300)) {
    MELDUNG = "Laufzeit Freischaltung abgelaufen";
    STOP (0);
  } 

//  Geschwindigkeit überprüfen**************************************************************************************************************************
 
 if ((f < (GESCHWINDIGKEIT*6)) && (AKTIVIERT==1) && (SPEED == 1) && (HOLD_AN_AUS == 1)) {
     MELDUNG = "Schalte_Auf";
    digitalWrite(OUT_PIN_AUF, HIGH);
    loopTime = millis(); // Laufzeit setzen
    loopTimeMAX = millis(); // Laufzeit setzen
    digitalWrite(BUZZER, LOW);
    SPEED = 0;        
  }

 if ((f < (GESCHWINDIGKEIT*6)) && (AKTIVIERT==1) && (SPEED == 1) && (HOLD_AN_AUS == 2)) {
     MELDUNG = "Schalte_Zu";
    digitalWrite(OUT_PIN_ZU, HIGH);
    loopTime = millis(); // Laufzeit setzen
    loopTimeMAX = millis(); // Laufzeit setzen
    digitalWrite(BUZZER, LOW);
    SPEED = 0;        
  }

if ((f > (GESCHWINDIGKEIT*6))&& (AKTIVIERT==1))
    {
    MELDUNG = "Zu schnell";
    digitalWrite(OUT_PIN_ZU, LOW); //Dach zu Stop
    digitalWrite(OUT_PIN_AUF, LOW); //Dach Auf Stop
    digitalWrite(BUZZER, HIGH);
    SPEED = 1;
    }

     count = 0;
     Timestamp = millis();
     interrupts();
  } 
}


//  Funktionen##############################################################################################################################################

// Frequenz
void ISR_f(){
  count++;
}

// Schalte alles AUS 
void STOP (boolean FZU) {
  F3HZ_AUS();
  digitalWrite(OUT_PIN_AUF, LOW);
  digitalWrite(OUT_PIN_ZU, LOW);
  LED = 0;
  AKTIVIERT = 0;
  HOLD1 = 0;
  HOLD_AN_AUS = 0;
  MELDUNG = "STOP Ausgefuehrt";
  MELDUNG = "STOP Ausgefuehrt";

 // Fenster schließen
 if ((FZU==1) && (FENSTERZU == 1)) {
  loopTimeFZU = millis(); // Laufzeit setzen
   FZU=0; 
   ZFZU=1;
   MELDUNG = "Fenster zu aktiviert";
   }
}

// schalte 3HZ Frequenz an
void F3HZ_AN() {
    digitalWrite(OUT_PIN_F, LOW); //ABS-Steuersignal blockieren 3Hz
    digitalWrite(OUT_PIN_F1, LOW); //Radfrequenz blockieren Geschwindigkeitssignal
    noInterrupts();
    TIMSK1 |= (1 << TOIE1); // Timer Overflow Interrupt aktivieren
    interrupts();
}

// schalte 3HZ Frequenz aus
void F3HZ_AUS() {
    noInterrupts();
    TIMSK1 &= (~(1 << TOIE1)); // Timer Overflow Interrupt deaktivieren
    interrupts();
    digitalWrite(9, LOW);  //Frequenzausgang Low schalten
    digitalWrite(OUT_PIN_F, HIGH); //ABS-Steuersignal durchschalten 3Hz
    digitalWrite(OUT_PIN_F1, HIGH); //Radfrequenz durchschalten Geschwindigkeitssignal
}

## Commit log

2017-08-15 Eagle circuit diagram
    [Dachmodul.sch]
2017-08-15 circuit diagram PDF
2017-08-18 Case for the module for your 3D printer
    [Gehaeuse_unten_Dachmodul.stl, Gehause_oben_Dachmodul.stl]
2017-08-19 Deutsche Beschreibung des Projekts
2018-05-23 Closed Issue with automatic closing the roof
    [Crossfire_Dachmodul-4.ino]
2018-05-23 Bedienung des Daches hat sich beim überschreiten der Geschwindigkeit geändert.
